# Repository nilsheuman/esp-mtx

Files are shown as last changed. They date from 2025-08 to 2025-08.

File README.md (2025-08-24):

# ESP32 Pixel Matrix

My little attempt on making a slim pcb for a pixel matrix with a Esp32 Nano board.

Made this last year to have on my sailing boat and it nicely show speed and bearing while mounted on the mast.

At first the display didn't seem so bright but on a longer distance it actually works well.

Below is a photo from sailing, the frame rate of the display does not match the shutter speed so all pixels are not lit. In real life it looks pretty good!

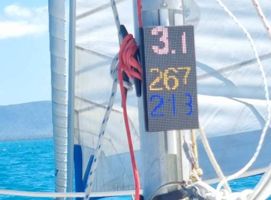
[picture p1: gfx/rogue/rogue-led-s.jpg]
Sailboat Display


I made a simple program to draw on the display passing json via a web server: [code/esp-ledpx](code/esp-ledpx).

Then I made another basic one to animate gif's uploaded via a web page. [code/esp-gif-mtx](code/esp-gif-mtx).

It was a while since I made a PCB and after having enough of the cable mayhem that connecting these boards up I ended up drawing a PCB and ordered it pre-soldered.

Below is most of the process documented, use it at your own risk...

# Assembly

The assembled display below.

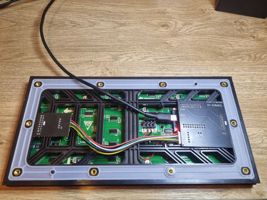
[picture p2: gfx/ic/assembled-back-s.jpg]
Assembled Back

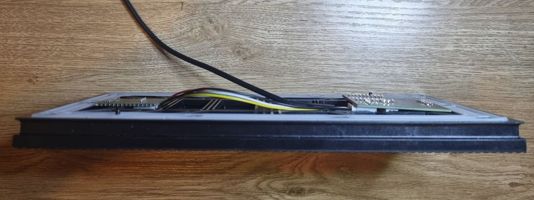
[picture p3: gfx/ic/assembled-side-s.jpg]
Assembled Back


The full kit, showing how some of the reinforcement brackets have been cut.

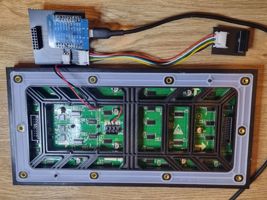
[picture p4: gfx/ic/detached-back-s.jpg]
Assembled Back


For extra slim fit, solder on the headers on the ESP, then remove the spacers and then cut the pins 2-3 mm. The cut pins be seen in the picture below.

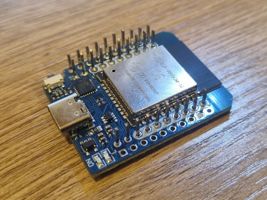
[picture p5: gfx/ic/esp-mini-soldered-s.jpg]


# Power

On the boat I powered it via a 12->5v converter and the ESP got it's power from Vin.

At home I instead powered the display from the ESP via USB which seems to work fine.

# Schematic

All files for the schematic with bom for ordering can be found under [schematic/pcb](schematic/pcb).

There are also a sketch on how to wire it up in [schematic/drawio](schematic/drawio)

With the esp mini pinout in [schematic/esp32mini](schematic/esp32mini)

## PCB

I created the schematic with [easyeda.com](https://easyeda.com) and had it manufactured and assembled with [jlcpcb.com](https://jlcpcb.com).

5 pieces was 30.04$.

I think it was some intro offer because on a later project the price was significantly higher.

The board should be cut along the drilled holes to split it in the two parts.

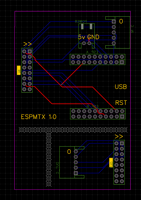
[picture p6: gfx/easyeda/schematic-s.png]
Schematic

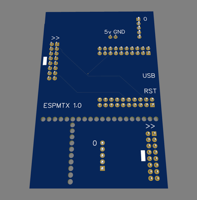
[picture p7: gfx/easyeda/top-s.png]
Top View 3D

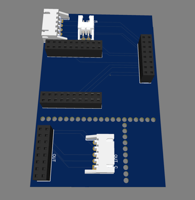
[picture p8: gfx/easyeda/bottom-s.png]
Bottom View 3D


## Parts

### Display
64x32 P4 Display (AU$23.11 + shipping + tax = AU$38)

ESP32 Mini

> P4 Outdoor SMD 256x128mm LED Display Module

https://www.aliexpress.com/item/1005003269876713.html

### ESP32 Mini
Microcontroller (AU$4.40 + tax = AU$4.80)

ESP32 Mini

> D1 Mini ESP32 ESP-32 WiFi+Bluetooth Internet of Things Development Board based ESP8266 Fully Functional

https://www.aliexpress.com/item/1005006414001036.html

### Diy Connectors
For creating the cable between the two connectors of the display

JST Diy

> 230pcs 2.54mm JST Connector Kit XH-2.54 2/3/4/5/6 Pin Male&Female Housing Connector Adapter Plug 2.54mm Pitch Wire Terminal Kit

https://www.aliexpress.com/item/1005006447186101.html

### Jst 5 pin cables

JST Connector

> 10Sets 2/3/4/5/6/7/8/9/10 Pin Pitch Male Female Plug Socket JST XH2.54 XH 2.54mm 15cm Wire Length 24AWG Wire Cable Connector

Color: `10Set 5Pin`

https://www.aliexpress.com/item/32964549472.html

### Jst 2 pin cables

JST Connector

> 10Sets 2/3/4/5/6/7/8/9/10 Pin Pitch Male Female Plug Socket JST XH2.54 XH 2.54mm 15cm Wire Length 24AWG Wire Cable Connector

Color: `10Set 2Pin`

https://www.aliexpress.com/item/32964549472.html

# Code

The code is a litte bit experimental and not something complete, but it is in usable state.

## ESP LedPx
Web server that allows simple drawing of text and basic shapes.
[code/esp-ledpx](code/esp-ledpx)

## ESP Gif Mtx

Web server that allows uploading of gif images, can set framerate in the interface.
[code/esp-gif-mtx](code/esp-gif-mtx)

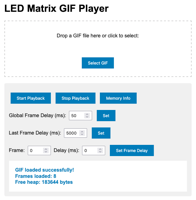
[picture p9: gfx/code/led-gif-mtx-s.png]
Gif UI


# References

Display Library and overview of how to wire the display.
https://github.com/2dom/PxMatrix/

Custom ESP8266 PCB
https://github.com/mike-rankin/ESP8266_RGB_Matrix_Cable_Version

ESP32 Mini Shield
https://www.tindie.com/products/brianlough/esp32-matrix-shield-mini-32/

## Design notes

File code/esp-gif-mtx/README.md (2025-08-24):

# ESP Gif Mtx

Renders GIFs to a pixelmatrix display of size 64x32

# Setup

Open the project with [platform.io](https://platformio.org/), then Upload and Monitor.

It sets up an access point with SSID `esp-pxmtx`:`password`, defined in [src/config.h](src/config.h).

Access web ui on `192.168.4.1` to configure a network.

The IP will be printed to serial and on the display once connected.

Then you can upload a GIF, it will be loaded into memory and drawn frame by frame.

# Development

The display updating timing is crucial so any blocking io will make it crash if having large images, the workaround was to pause the display routine while uploading and loading all frames to memory, and then be able to draw them faster (~5ms per frame).

To update the webpage, edit [resources/index.html](resources/index.html) and run the [scripts/gen_index.sh](scripts/gen_index.sh) to generate [src/index_html.h](src/index_html.h)

To simplify development with LLMs there is a script in [scripts/read_files.sh](scripts/read_files.sh) to extract all content with filenames. They however seem to be a bit clueless and destructive changing the code...

# Gif Resources

Rotate and crop
https://ezgif.com/

Small gifs
https://www.animatedimages.org/

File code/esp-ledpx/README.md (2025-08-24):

# ESP Led Px

Basic sketch to run a web server and take commands for text and basic shapes to be displayed on a pixel display.

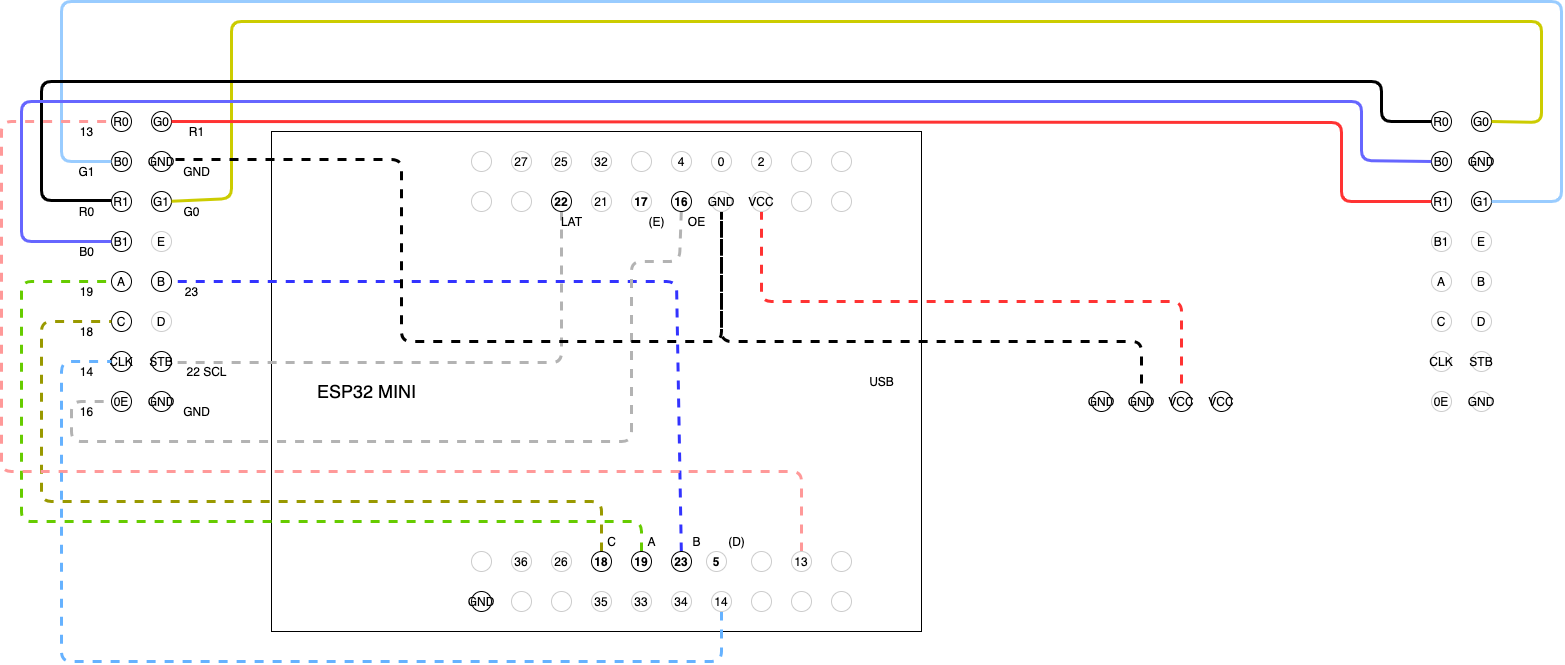
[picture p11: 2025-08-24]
schematic/drawio/esp32-mini-led-display.png

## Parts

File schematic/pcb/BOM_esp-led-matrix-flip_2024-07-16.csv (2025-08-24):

ID | Name | Designator | Footprint | Quantity | Manufacturer Part | Manufacturer | Supplier | Supplier Part | Price
1 | ZX-PM2.54-2-10PY | ESP_A,ESP_B | HDR-TH_20P-P2.54-V-F-R2-C10-S2.54 | 2 | ZX-PM2.54-2-10PY | Megastar(兆星) | LCSC | C7499346 | 0.248
2 | Header-Female-2.54_2x8 | IN,OUT | HDR-TH_16P-P2.54-V-F-R2-C8-S2.54 | 2 | 2.54-2*8P母 | BOOMELE(博穆精密) | LCSC | C30734 | 0.112
3 | S5B-XH-A-1 (LF)(SN) | IN_C,OUT_C | CONN-TH_S5B-XH-A-1-LF-SN | 2 | S5B-XH-A-1(LF)(SN) | JST | LCSC | C163038 | 0.099
4 | S2B-XH-A-(LF)(SN) | POWER | CONN-TH_S2B-XH-A-LF-SN | 1 | S2B-XH-A(LF)(SN) | JST | LCSC | C157931 | 0.069

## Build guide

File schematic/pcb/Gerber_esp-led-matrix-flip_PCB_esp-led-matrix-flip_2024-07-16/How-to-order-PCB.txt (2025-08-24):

How to Order PCB

Please refer to:
https://docs.easyeda.com/en/PCB/Order-PCB

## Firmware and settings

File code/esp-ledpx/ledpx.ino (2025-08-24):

#include <Arduino.h>
#include <WebServer.h>
#include <ArduinoJson.h>

#include <WiFiManager.h>


#include <Adafruit_GFX.h>
#include <Adafruit_SPITFT.h>
#include <Adafruit_SPITFT_Macros.h>
#include <gfxfont.h>
#include <Fonts/FreeMono24pt7b.h>
#include <Fonts/FreeMonoBold18pt7b.h>
#include <Fonts/FreeMonoBold12pt7b.h>
#include <Fonts/Picopixel.h>
#include <Fonts/FreeSansBold18pt7b.h>
#include <Fonts/FreeSerif18pt7b.h>
#include <Fonts/FreeSansBold12pt7b.h>
#include <Fonts/FreeSans9pt7b.h>


// This is how many color levels the display shows - the more the slower the update
//#define PxMATRIX_COLOR_DEPTH 8
#define PxMATRIX_COLOR_DEPTH 4

// Defines the buffer height / the maximum height of the matrix
// #define PxMATRIX_MAX_HEIGHT 64
#define PxMATRIX_MAX_HEIGHT 32

// Defines the buffer width / the maximum width of the matrix
#define PxMATRIX_MAX_WIDTH 64

// Defines how long we display things by default
//#define PxMATRIX_DEFAULT_SHOWTIME 30

// Defines the speed of the SPI bus (reducing this may help if you experience noisy images)
// #define PxMATRIX_SPI_FREQUENCY 20000000
#define PxMATRIX_SPI_FREQUENCY 10000000

// Creates a second buffer for backround drawing (doubles the required RAM)
#define PxMATRIX_double_buffer true

#include "PxMatrix.h"

// Pins for LED MATRIX
#ifdef ESP32

#define P_LAT 22
#define P_A 19
#define P_B 23
#define P_C 18
#define P_D 5 // N/C
// #define P_E 15
#define P_E 17 // N/C
// #define P_OE 2
#define P_OE 16
hw_timer_t * timer = NULL;
portMUX_TYPE timerMux = portMUX_INITIALIZER_UNLOCKED;

#endif

#ifdef ESP8266

#include <Ticker.h>
Ticker display_ticker;
#define P_LAT 16
#define P_A 5
#define P_B 4
#define P_C 15
#define P_D 12
#define P_E 0
#define P_OE 2

#endif

// #define matrix_width 32
// #define matrix_height 16
#define matrix_width 64
#define matrix_height 32

// This defines the 'on' time of the display is us. The larger this number,
// the brighter the display. If too large the ESP will crash
uint8_t display_draw_time=60; //30-70 is usually fine

// PxMATRIX display(32,16,P_LAT, P_OE,P_A,P_B,P_C);
PxMATRIX display(64,32,P_LAT, P_OE,P_A,P_B,P_C,P_D);
//PxMATRIX display(64,64,P_LAT, P_OE,P_A,P_B,P_C,P_D,P_E);

// Some standard colors
uint16_t myRED = display.color565(255, 0, 0);
uint16_t myGREEN = display.color565(0, 100, 0);
uint16_t myBLUE = display.color565(0, 0, 255);
uint16_t myWHITE = display.color565(255, 255, 255);
uint16_t myYELLOW = display.color565(255, 255, 0);
uint16_t myCYAN = display.color565(0, 255, 255);
uint16_t myMAGENTA = display.color565(255, 0, 255);
uint16_t myBLACK = display.color565(0, 0, 0);
uint16_t myGRAY = display.color565(50, 50, 50);
uint16_t myDARKGRAY = display.color565(25, 25, 25);
uint16_t myLIGHTGRAY = display.color565(150, 150, 150);
uint16_t myLIGHTBLUE = display.color565(75, 75, 255);

#define num_colors 12
uint16_t myCOLORS[num_colors] = {myWHITE, myBLACK, myRED, myGREEN, myBLUE, myYELLOW, myCYAN, myMAGENTA, myGRAY, myDARKGRAY, myLIGHTGRAY, myLIGHTBLUE};
//                                     0.       1.     2.       3.      4.        5.      6.         7.      8.          9.          10.          11.

int x = 0;
int y = 0;
int width = 0;
int height = 0;
uint16_t myColor = display.color565(0, 0, 0);
boolean fill = false;
String content = "";
int size = 0;
int font = 0;
int brightness = 25;
int rotation = 0;

#ifdef ESP8266
// ISR for display refresh
void display_updater()
{
  display.display(display_draw_time);
}
#endif

#ifdef ESP32
void IRAM_ATTR display_updater(){
  // Increment the counter and set the time of ISR
  portENTER_CRITICAL_ISR(&timerMux);
  display.display(display_draw_time);
  portEXIT_CRITICAL_ISR(&timerMux);
}
#endif


void display_update_enable(bool is_enable)
{

#ifdef ESP8266
  if (is_enable)
    display_ticker.attach(0.004, display_updater);
  else
    display_ticker.detach();
#endif

#ifdef ESP32
  if (is_enable)
  {
    timer = timerBegin(0, 80, true);
    timerAttachInterrupt(timer, &display_updater, true);
    timerAlarmWrite(timer, 4000, true);
    timerAlarmEnable(timer);
  }
  else
  {
    timerDetachInterrupt(timer);
    timerAlarmDisable(timer);
  }
#endif
}




// Web server running on port 80
WebServer server(80);


unsigned long lastTimeRan;

StaticJsonDocument<1024> jsonDocument;

char buffer[1024];



void handleLine() {
  Serial.println("line");
  
  uint16_t x1 = x + width;
  uint16_t y1 = y + height;
  display.drawLine(x, y, x1, y1, myColor);
}

void handleRect() {
  Serial.println("rect");

  if (fill) {
    display.fillRect(x, y, width, height, myColor);
  } else {
    display.drawRect(x, y, width, height, myColor);
  }
}

void handleCircle() {
  Serial.println("circle");

  if (fill) {
    display.fillCircle(x, y, width, myColor);
  } else {
    display.drawCircle(x, y, width, myColor);
  }
}

void handleText() {
  Serial.println("text");
  
  display.setTextColor(myColor, myBLACK);

  if (font == 0) {
    display.setFont();
  } else if (font == 1) {
    display.setFont(&FreeMonoBold18pt7b);
  } else if (font == 2) {
    display.setFont(&FreeMono24pt7b);
  } else if (font == 3) {
    display.setFont(&Picopixel);
  } else if (font == 4) {
    display.setFont(&FreeMonoBold12pt7b); // added
  } else if (font == 5) {
    display.setFont(&FreeSansBold18pt7b); // added
  } else if (font == 6) {
    display.setFont(&FreeSerif18pt7b); // added
  } else if (font == 7) {
    display.setFont(&FreeSansBold12pt7b); // added
  } else if (font == 8) {
    display.setFont(&FreeSans9pt7b); // added
  }


  // display.setTextWrap(false);  // we don't wrap text so it scrolls nicely
  display.setTextSize(size);

  display.setCursor(x,y);
  display.print(content);
}

void handleSetup() {
  Serial.println("setup");
  
  display.setBrightness(brightness);

  display.setRotation(rotation); // 0 1 2 3 ?
}

void handleMulti() {

  // can handle 6 objects

  if (server.hasArg("plain") == false) {
    //handle error here
  }
  String body = server.arg("plain");
  deserializeJson(jsonDocument, body);

  // Iterate through the array
  for (JsonVariant obj : jsonDocument.as<JsonArray>()) {
    const char* type = obj["type"];
    
    x = obj["x"];
    y = obj["y"];
    width = obj["width"];
    height = obj["height"];
    int color = obj["color"];
    boolean clear = obj["clear"];
      
    fill = obj["fill"]; // fillrect/circle
    String content1 = obj["content"]; // TODO
    content = content1;
    size = obj["size"]; // scales font
    font = obj["font"]; // different font size and types
    brightness = obj["brightness"];
    rotation = obj["rotation"];

    if (clear) {
      display.clearDisplay();
    }

    if (color >= 0 && color < num_colors) {
      myColor = myCOLORS[color];
    }
    
    // Check the type and execute the corresponding function
    if (strcmp(type, "text") == 0) {
      handleText();
    } else if (strcmp(type, "rect") == 0) {
      handleRect();
    } else if (strcmp(type, "circle") == 0) {
      handleCircle();
    } else if (strcmp(type, "line") == 0) {
      handleLine();
    } else if (strcmp(type, "setup") == 0) {
      handleSetup();
    } else {
      Serial.println("Unknown type");
    }
  }

  server.send(200, "application/json", "{\"cmd\":\"multi\"}");
}

 
void addJsonObject(char *name) {
  JsonObject obj = jsonDocument.createNestedObject();
  obj["name"] = name;
}

const char* htmlCode = R"(
<html>
<meta name=viewport content=width=device-width,initial-scale=1,user-scalable=no>
<script type=text/javascript>
	function send(type) {
		const data = [{
			content: document.getElementById(type + '_content').value,
			x: document.getElementById(type + '_x').value,
			y: document.getElementById(type + '_y').value,
			clear: document.getElementById(type + '_clear').checked,
			font: parseInt(document.getElementById(type + '_font').value),
			color: parseInt(document.getElementById(type + '_color').value),
			size: parseInt(document.getElementById(type + '_size').value),
			width: parseInt(document.getElementById(type + '_width').value),
			height: parseInt(document.getElementById(type + '_height').value),
			fill: document.getElementById(type + '_fill').checked ? 1 : 0,
			brightness: parseInt(document.getElementById(type + '_brightness').value),
			rotation: parseInt(document.getElementById(type + '_rotation').value),
			type: type
		}]
		api(data)
	}

	function api(postData) {
		const url = 'http://' + location.host + '/multi';
		const requestOptions = {method: 'POST',headers: {'Content-Type': 'application/json'}, body: JSON.stringify(postData)};
		fetch(url, requestOptions)
	}

	function writeFonts() {
		const colors = ['Default','FreeMonoBold18pt7b','FreeMono24pt7b','Picopixel','FreeMonoBold12pt7b','FreeSansBold18pt7b','FreeSerif18pt7b','FreeSansBold12pt7b','FreeSans9pt7b']
		document.write(colors.map((c, i) => '<option value='+i+'>' + c + '</option>'))
	}

	function writeColors() {
		const colors = ['White','Black','Red','Green','Blue','Yellow','Cyan','Magenta','Gray', 'Dark Gray', 'Light Gray', 'Light Blue']
		document.write(colors.map((c, i) => '<option value='+i+'>' + c + '</option>'))
	}
</script>
<style>
	input, select {
		/*
		margin-left: 20px;
		margin-bottom: 5px;*/
	}
	input[type=button] {
		margin-left: 100px;
	}
	th {
		text-align: left;
	}
</style>


<table>
<tr><th colspan=2>Text <input type=button value=update onclick=send('text')></th></tr>
<tr><td>Content:</td><td><input id=text_content type=text value=content></td></tr>
<tr><td>X,Y:</td><td><input id=text_x type=text value=0 size=3>,<input id=text_y type=text value=0 size=3></td></tr>
<tr><td>Font:</td><td><select id=text_font><script>writeFonts()</script></select></td></tr>
<tr><td>Color:</td><td><select id=text_color><script>writeColors()</script></select></td></tr>
<tr><td>Size:</td><td><input id=text_size type=text value=1 size=3></td></tr>
<tr><td>Clear:</td><td><input id=text_clear type=checkbox></td></tr>

<input id=text_width type=hidden value=1>
<input id=text_height type=hidden value=1>
<input id=text_fill type=hidden value=0>
<input id=text_brightness type=hidden value=25>
<input id=text_rotation type=hidden value=0>


<tr><th colspan=2><br/>Line <input type=button value=update onclick=send('line')></th></tr>
<tr><td>X,Y:</td><td><input id=line_x type=text value=0 size=3>,<input id=line_y type=text value=0 size=3></td></tr>
<tr><td>Width, Height:</td><td><input id=line_width type=text value=10 size=3>,<input id=line_height type=text value=50 size=3></td></tr>
<tr><td>Fill:</td><td><input id=line_fill type=checkbox></td></tr>
<tr><td>Color:</td><td><select id=line_color><script>writeColors()</script></select></td></tr>
<tr><td>Clear:</td><td><input id=line_clear type=checkbox></td></tr>


<input id=line_content type=hidden value=0>
<input id=line_size type=hidden value=0>
<input id=line_font type=hidden value=0>
<input id=line_brightness type=hidden value=25>
<input id=line_rotation type=hidden value=0>


<tr><th colspan=2><br/>Rect <input type=button value=update onclick=send('rect')></th></tr>
<tr><td>X,Y:</td><td><input id=rect_x type=text value=0 size=3>,<input id=rect_y type=text value=0 size=3></td></tr>
<tr><td>Width, Height:</td><td><input id=rect_width type=text value=10 size=3>,<input id=rect_height type=text value=50 size=3></td></tr>
<tr><td>Fill:</td><td><input id=rect_fill type=checkbox></td></tr>
<tr><td>Color:</td><td><select id=rect_color><script>writeColors()</script></select></td></tr>
<tr><td>Clear:</td><td><input id=rect_clear type=checkbox></td></tr>

<input id=rect_content type=hidden value=0>
<input id=rect_size type=hidden value=0>
<input id=rect_font type=hidden value=0>
<input id=rect_brightness type=hidden value=25>
<input id=rect_rotation type=hidden value=0>



<tr><th colspan=2><br/>Circle <input type=button value=update onclick=send('circle')></th></tr>
<tr><td>X,Y:</td><td><input id=circle_x type=text value=0 size=3>,<input id=circle_y type=text value=0 size=3></td></tr>
<tr><td>Width, Height:</td><td><input id=circle_width type=text value=10 size=3>,<input id=circle_height type=text value=50 size=3></td></tr>
<tr><td>Fill:</td><td><input id=circle_fill type=checkbox></td></tr>
<tr><td>Color:</td><td><select id=circle_color><script>writeColors()</script></select></td></tr>
<tr><td>Clear:</td><td><input id=circle_clear type=checkbox></td></tr>

<input id=circle_content type=hidden value=0>
<input id=circle_size type=hidden value=0>
<input id=circle_font type=hidden value=0>
<input id=circle_brightness type=hidden value=25>
<input id=circle_rotation type=hidden value=0>


<tr><th colspan=2><br/>Setup <input type=button value=update onclick=send('setup')></th></tr>
<tr><td>Brightness:</td><td><input id=setup_brightness type=text value=25 size=3></td></tr>
<tr><td>Rotation:</td><td><select id=setup_rotation><option>0</option><option>1</option><option>2</option><option>3</option></select></td></tr>
<tr><td>Clear:</td><td><input id=setup_clear type=checkbox></td></tr>

<input id=setup_content type=hidden value=0 size=3>
<input id=setup_x type=hidden value=0 size=3>
<input id=setup_y type=hidden value=0 size=3>
<input id=setup_font type=hidden value=0>
<input id=setup_color type=hidden value=0>
<input id=setup_size type=hidden value=1 size=3>

<input id=setup_width type=hidden value=1>
<input id=setup_height type=hidden value=1>
<input id=setup_fill type=hidden value=0>

</table>

</html>


)";




void getRoot() {
  Serial.println("Get ");
  // jsonDocument.clear(); // Clear json buffer
  // addJsonObject("PxMatrix");
  
  // serializeJson(jsonDocument, buffer);
  // server.send(200, "application/json", buffer);

  server.send(200, "text/html", htmlCode);
}

void sendCrossOriginHeader() {

  // server.sendHeader("Access-Control-Allow-Origin", "*"));
  // server.sendHeader("Access-Control-Max-Age", "600"));
  // server.sendHeader("Access-Control-Allow-Methods", "PUT,POST,GET,OPTIONS"));
  // server.sendHeader("Access-Control-Allow-Headers", "*"));

  server.send(204);
}

void setupApi() {
  server.enableCORS();

  server.on("/", HTTP_OPTIONS, sendCrossOriginHeader);
  server.on("/setup", HTTP_OPTIONS, sendCrossOriginHeader);
  server.on("/multi", HTTP_OPTIONS, sendCrossOriginHeader);

  server.on("/", getRoot);
  server.on("/setup", HTTP_POST, handleSetup);
  server.on("/multi", HTTP_POST, handleMulti);
 
  // start server
  server.begin();
}


void setupDisplay() {

  // Define your display layout here, e.g. 1/8 step, and optional SPI pins begin(row_pattern, CLK, MOSI, MISO, SS)
  display.begin(8);

  // Define multiplex implemention here {BINARY, STRAIGHT} (default is BINARY)
  display.setMuxPattern(BINARY);

  // Set the multiplex pattern {LINE, ZIGZAG,ZZAGG, ZAGGIZ, WZAGZIG, VZAG, ZAGZIG} (default is LINE)
  display.setScanPattern(LINE);

  // Set the number of panels that make up the display area width (default is 1)
  display.setPanelsWidth(2);

  display.setScanPattern(WZAGZIG2);

  display_update_enable(true);

  brightness = 50;
  rotation = 1;
  handleSetup();

  // Set the brightness of the panels (default is 255)
  // display.setBrightness(50);

  display.clearDisplay();
  display.setTextColor(myWHITE, myBLACK);
  display.setCursor(1,1);
  display.print("ROGUE");
}

void setupWifi() {

  WiFi.mode(WIFI_STA); // explicitly set mode, esp defaults to STA+AP
  // it is a good practice to make sure your code sets wifi mode how you want it.

  //WiFiManager, Local intialization. Once its business is done, there is no need to keep it around
  WiFiManager wm;

  // reset settings - wipe stored credentials for testing
  // these are stored by the esp library
  // wm.resetSettings();  

  // Automatically connect using saved credentials,
  // if connection fails, it starts an access point with the specified name ( "AutoConnectAP"),
  // if empty will auto generate SSID, if password is blank it will be anonymous AP (wm.autoConnect())
  // then goes into a blocking loop awaiting configuration and will return success result

  bool res;
  // res = wm.autoConnect(); // auto generated AP name from chipid
  // res = wm.autoConnect("AutoConnectAP"); // anonymous ap
  res = wm.autoConnect("ledpx","password"); // password protected ap

  if(!res) {
      Serial.println("Failed to connect");
      ESP.restart();
  } else {
      //if you get here you have connected to the WiFi    
      Serial.println("Connected...yeey :)");
  }

  setupApi();
}

void showIp() {
  Serial.print("local ip: ");
  Serial.println(WiFi.localIP());
  
  // display.setFont(&Picopixel);
  display.setTextColor(myYELLOW, myBLACK);
  display.setCursor(1,20);
  display.print(WiFi.localIP());
}

void setup() {

  Serial.begin(115200);
  // This delay gives the chance to wait for a Serial Monitor without blocking if none is found
  delay(2500); 

// has to be before setupDisplay or xQueueSemaphoreTake queue.c:1554 error
  Serial.println("setupWifi");
  setupWifi();

  Serial.println("setupDisplay");
  setupDisplay();

  Serial.println("showIp");
  showIp();
}

void loop() {
  // put your main code here, to run repeatedly:
  server.handleClient();
}

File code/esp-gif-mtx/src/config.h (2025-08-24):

#ifndef CONFIG_H
#define CONFIG_H

// Matrix display configuration
#define PxMATRIX_COLOR_DEPTH 4
#define PxMATRIX_MAX_HEIGHT 32
#define PxMATRIX_MAX_WIDTH 64
#define PxMATRIX_SPI_FREQUENCY 10000000
#define PxMATRIX_double_buffer true

// Matrix dimensions
#define matrix_width 64
#define matrix_height 32

// Display timing - controls brightness (30-70 is usually fine)
#define DISPLAY_DRAW_TIME 60

// ESP32 Pin definitions for LED Matrix
#ifdef ESP32
#define P_LAT 22
#define P_A 19
#define P_B 23
#define P_C 18
#define P_D 5
#define P_E 17
#define P_OE 16
#endif

// Color definitions
#define NUM_COLORS 8

// Wifi/Accesspoint
#define AP_SSID "esp-pxmtx"
#define AP_PASSWORD "password"

#endif // CONFIG_H

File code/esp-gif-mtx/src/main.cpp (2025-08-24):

#include <Arduino.h>
#include <WebServer.h>
#include "display_driver.h"
#include "network.h"
#include "web_server.h"

#include <LittleFS.h>

void setupFilesystem() {
    if (!LittleFS.begin()) {
        Serial.println("LittleFS Mount Failed");
        
        if (LittleFS.format()) {
            Serial.println("LittleFS Formatted");
            LittleFS.begin();
        }
    } else {
        Serial.println("LittleFS Mounted");
    }
}

void setup() {

  Serial.begin(115200);
  
  setupFilesystem();
  setupWifi();
  setupDisplay();
  setupApi();

  showIp();
}

void loop() {
  serverLoop();
}

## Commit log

2025-08-24 code esp-ledpx
2025-08-24 code esp-gif-mtx
    [partitions.csv]
2025-08-24 readme touch up crop rogue image screenshot led-gif, fix read_files include src properly
